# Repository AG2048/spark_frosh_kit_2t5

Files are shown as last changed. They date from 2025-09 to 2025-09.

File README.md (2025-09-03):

# Spark Design Club F!rosh Kit 2T5
F!rosh kit PCB design and programming files for F!rosh 2T5.

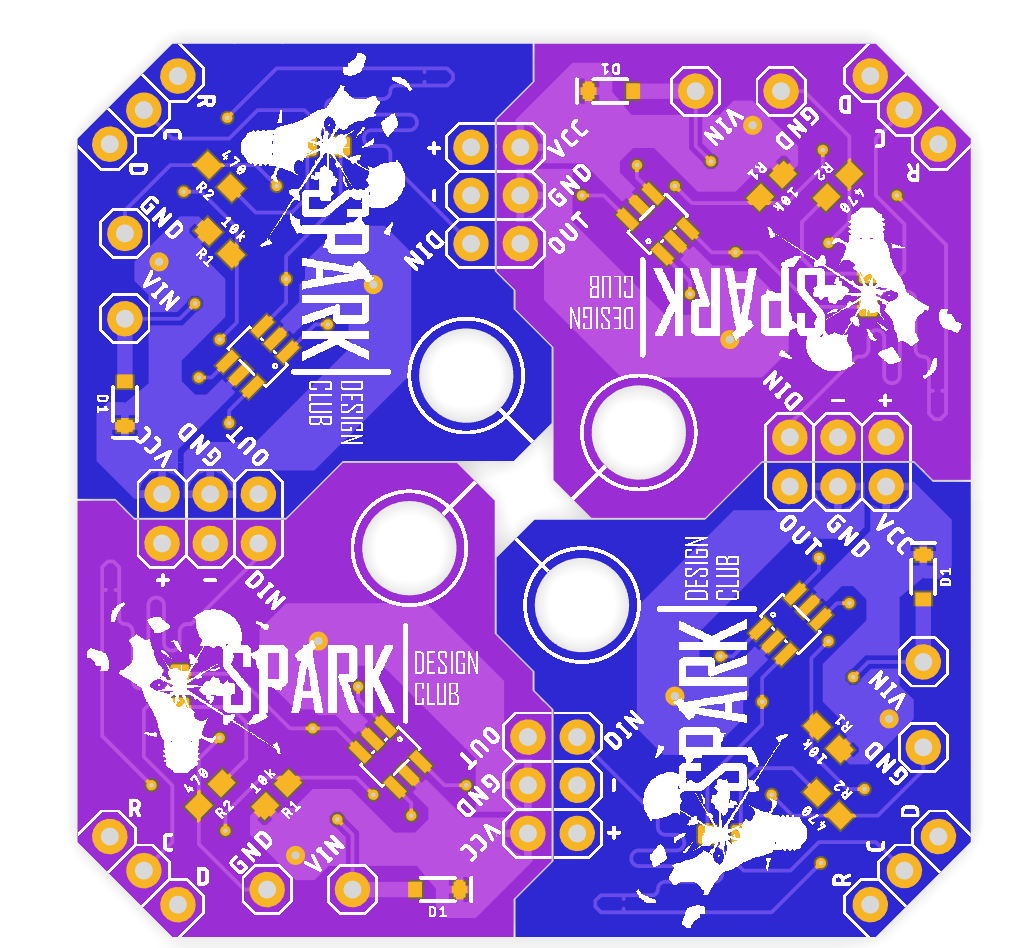
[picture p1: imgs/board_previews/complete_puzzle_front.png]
F!rosh Kit 2T5


# Description
The Spark F!rosh Kit 2T5 is a set of custom PCB designs featuring the Spark Design Club logo and branding. It is designed to act as a puzzle piece with two different color options. Each board of one colour can piece with two other boards of the other colour on two edges, and with 4 boards together, they form a loop in the shape of a large square!

This PCB features the ATTiny10 microcontroller, a small and versatile chip that can be easily powered, perfect for small, low-power applications like this F!rosh Kit PCB. Each board can communicate with the "downstream" board it is connected to and share power, with the ability to identify if the board itself has the "source power". 

The boards alone is a durable design for a keychain, showcasing your interest in electronics and design. When soldered, it can be used as a simple LED light source when powered. 

The real complex design of the boards comes into play when 4 soldered boards come together and form the larger square shape. When powered, these boards can be used to display more complex patterns!

The objective of this design is to make a cool-looking PCB, while also using its puzzle-like design to encourage F!rosh this year to meet new friends (reference: some old coca-cola commercial that did this...)

# File Structure
- `board_design_files/`: Contains the PCB design files for the F!rosh 2T5 kit. The BOM can also be found somewhere in this directory.
- `frosh_kit_program/`: Contains the Arduino program files for the F!rosh 2T5 kit.
- `imgs/`: Contains images related to the F!rosh 2T5 kit.
- `programming_resources/`: Contains resources for programming the ATTiny10 microcontroller. These files may be produced by other people. 

# Programming
The ATTiny10 microcontroller used in the F!rosh Kit can be programmed using the Tiny Programming Interface (TPI). The instruction to program the ATTiny10 using TPI was originally found on [this tutorial](https://make.kosakalab.com/make/electronic-work/arduio_tpi_en/). Unfortunately, as of September 1, 2025, this tutorial site is no longer available. Therefore, I have provided the necessary instructions below.

## Wire Connections
1. Prepare an Arduino UNO and 4 resistors (anywhere from 220Ω to 1kΩ should work).
2. Connect pin 10, 11, 12, and 13 of the Arduino UNO to the 4 resistors. Respectively, the other end of the resistors connected to pins 10, 11 and 12, and 13 represents `RESET`, `TPIDATA`, and `TPICLK`. (Image from the original tutorial)
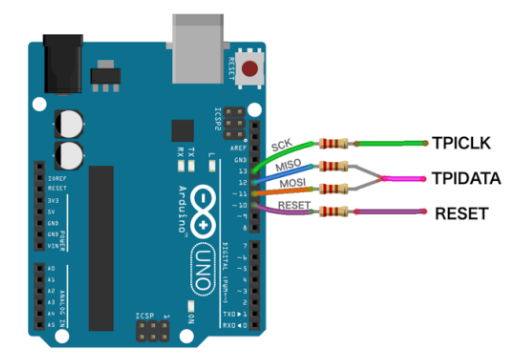
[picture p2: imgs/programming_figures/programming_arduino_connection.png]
Arduino Programming Connections

3. Connect `RESET` to the `R` pin, `TPIDATA` to the `D` pin, and `TPICLK` to the `C` pin. Also connect 5V to `VIN` or `+` or `VCC`, and ground to `GND` or `-`. The pins are visible from the front of the board:
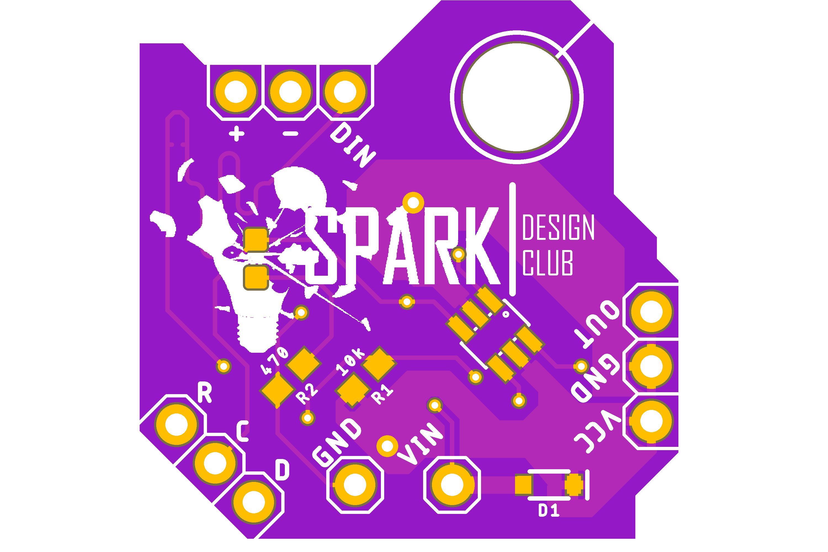
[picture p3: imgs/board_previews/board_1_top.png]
Board 1 Front View

- Note, if it's hard to connect to the `R`, `C`, `D` pins, you can connect `TPIDATA` to the `DIN` pin, and connect the `TPICLK` to the `CLK` pin. 

## Programming Environment Setup
1. Download the [modified Arduino programmer](programming_resources/ATtiny4_5_9_10_20_40Programmer_2/) obtained from the original tutorial.
2. Using the Arduino IDE, upload this sketch to the Arduino UNO.
3. Copy the following package.json URL to the Arduino IDE's Additional Board Manager URLs: `https://raw.githubusercontent.com/AG2048/spark_frosh_kit_2t5/refs/heads/main/programming_resources/package_bitDuino10-arduinoTPI_index.json` and click `OK`. (The original json file link is [here](https://kimio-kosaka.github.io/bitDuino10-arduinoTPI/package_bitDuino10-arduinoTPI_index.json), but a bug fix was needed to make this work on newer versions of Arduino IDE / AVR Board Packages)
4. Go to Tools > Board > Boards Manager, search for `bitduino`, and install `bitDuino10-aTPI`.
5. In Tools > Board, select `ATtiny10(bitDuino10-arduinoTPI)` as the active board, and select the port that the Arduino UNO is connected to. 

## Programming the ATTiny10
1. Load the (F!rosh Kit Program)[frosh_kit_program/] into the Arduino IDE.
2. Click the "Upload" button. 

## Notes:
The original package had a bug with the avr-gcc compiler version. Originally, it has to be set to version `5.4.0-atmel3.6.1-arduino2`, which forces users to use Arduino IDE 1.8.9 or less and version 1.6.23 of the Arduino AVR Boards platform. Details of this bug can be found in this [issue thread](https://github.com/kimio-kosaka/bitDuino10-arduinoTPI/issues/4#issuecomment-1046231772). 

As a fix, I adopted the solution mentioned in the issue thread, and made my [own copy of the package json file](programming_resources/package_bitDuino10-arduinoTPI_index.json) that adds the following package dependency specifications:

```json
      "toolsDependencies": [
        {
          "packager": "arduino",
          "name": "avr-gcc",
          "version": "5.4.0-atmel3.6.1-arduino2"
        },
        {
          "packager": "bitDuino10-aTPI",
          "name": "avrboy",
          "version": "1.0.1"
        }
      ]
```

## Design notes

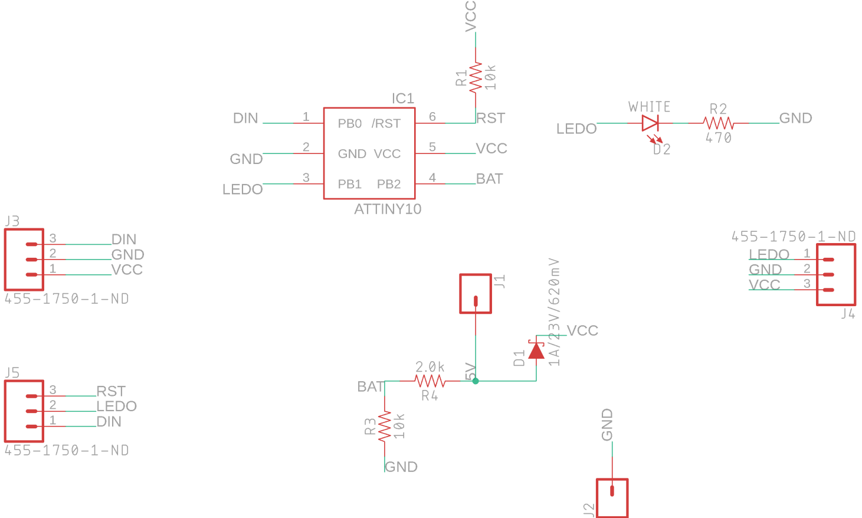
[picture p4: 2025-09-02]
imgs/schematics/schematic.png

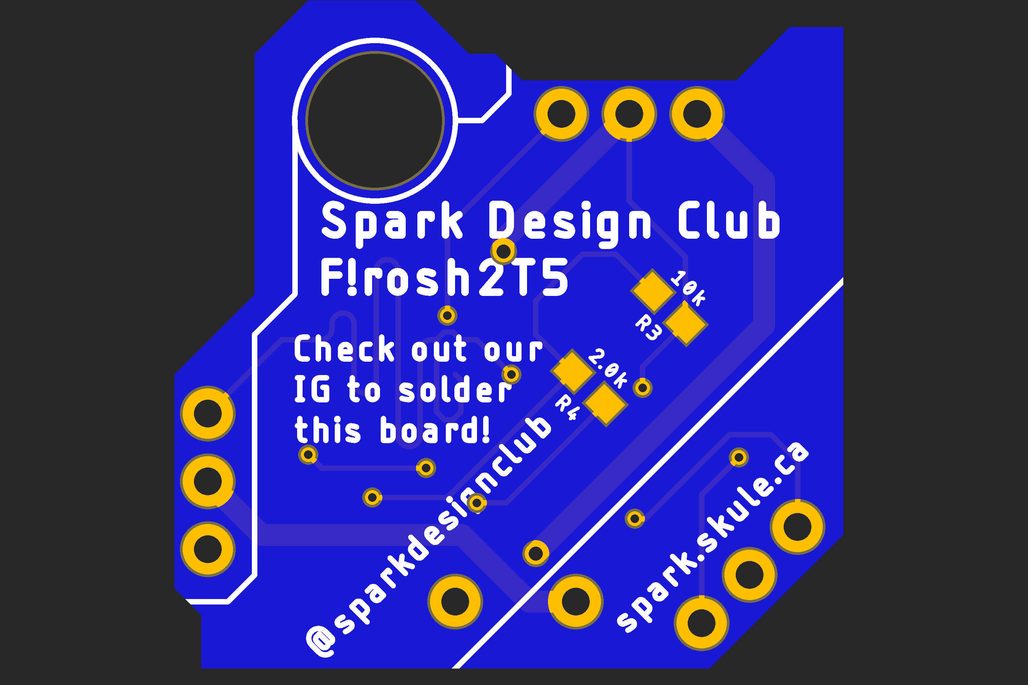
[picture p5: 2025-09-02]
imgs/board_previews/board_2_back.png

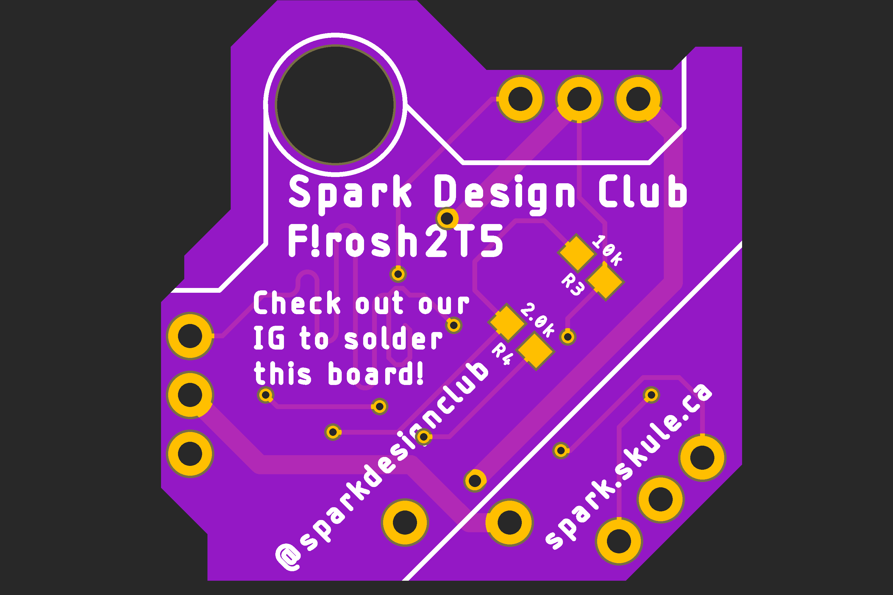
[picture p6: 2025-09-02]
imgs/board_previews/board_1_back.png

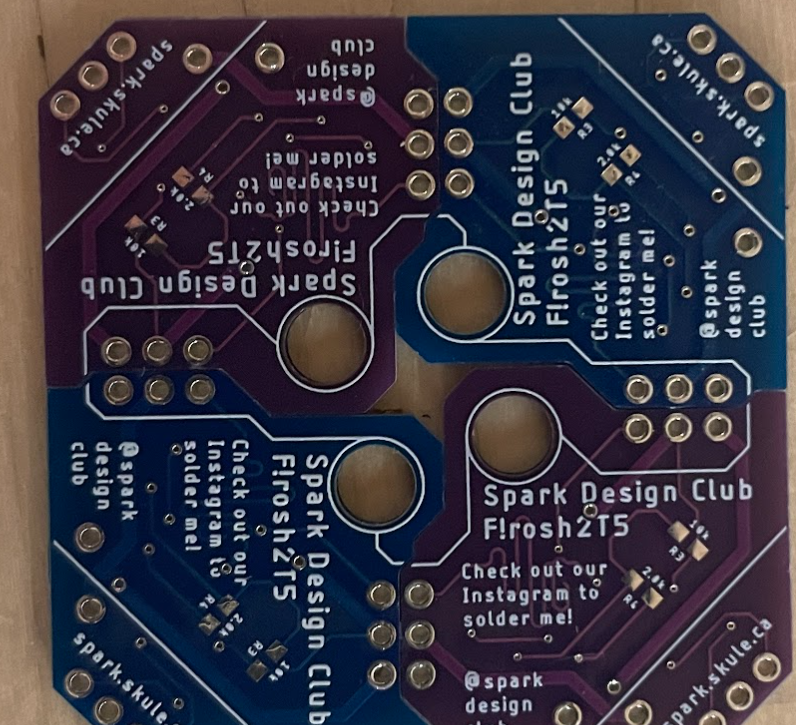
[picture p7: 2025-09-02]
imgs/produced_boards/four_boards_pieced_back.png

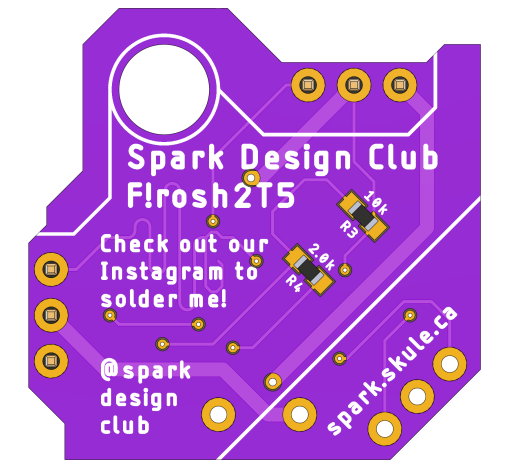
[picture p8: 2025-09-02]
imgs/board_previews/board_1_fusion_preview_back.png

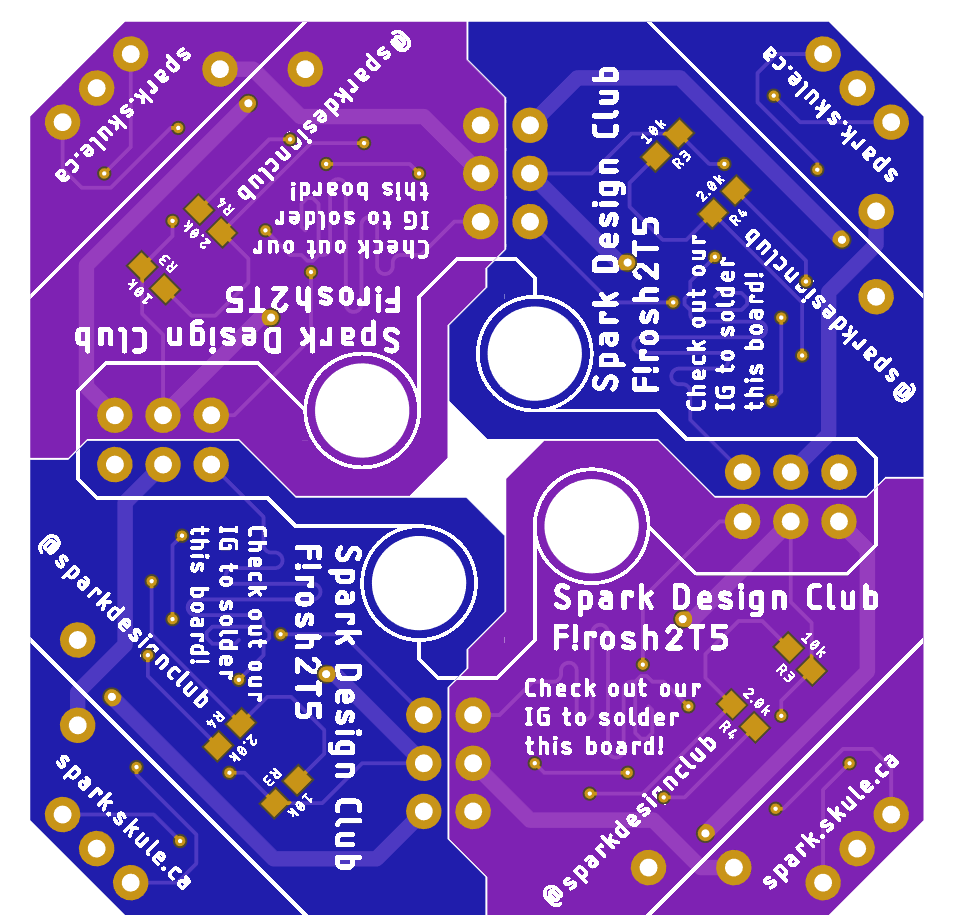
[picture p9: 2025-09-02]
imgs/board_previews/complete_puzzle_back.png

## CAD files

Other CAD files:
board_design_files/3d_models/SPARK_PCB_2025_BRD_1_3D.f3d
board_design_files/3d_models/SPARK_PCB_2025_BRD_2_3D.f3d

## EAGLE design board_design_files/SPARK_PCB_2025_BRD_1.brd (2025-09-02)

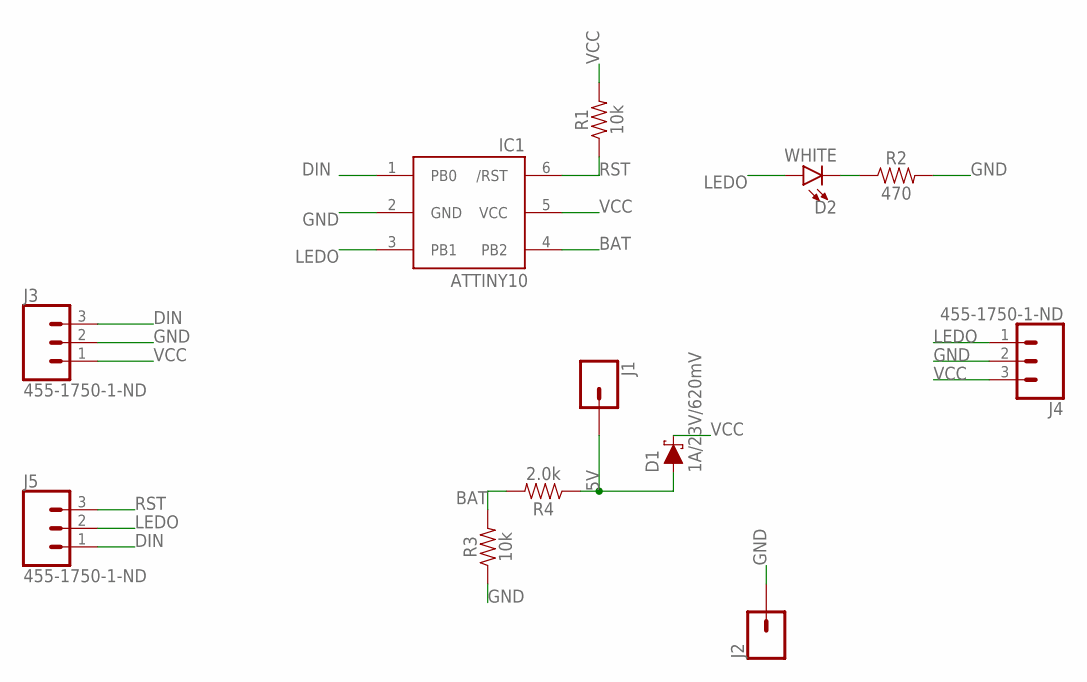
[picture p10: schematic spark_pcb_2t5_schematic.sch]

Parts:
D1: 1A/23V/620mV; SOD-323
D2: WHITE; LED-0603
IC1: ATTINY10; SOT23-6
J1, J2: CONN_01; 1X01
J3, J4, J5: 455-1750-1-ND; 1X03
R1, R3: 10k; 0603
R2: 470; 0603
R4: 2.0k; 0603

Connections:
5V: D1.A, J1.1, R4.1
BAT: IC1.4 (PB2), R3.2, R4.2
DIN: IC1.1 (PB0), J3.3, J5.1
GND: IC1.2 (GND), J2.1, J3.2, J4.2, R2.2, R3.1
LEDO: D2.A, IC1.3 (PB1), J4.1, J5.2
unnamed: D2.C, R2.1
RST: IC1.6 (/RST), J5.3, R1.1
VCC: D1.C, IC1.5 (VCC), J3.1, J4.3, R1.2

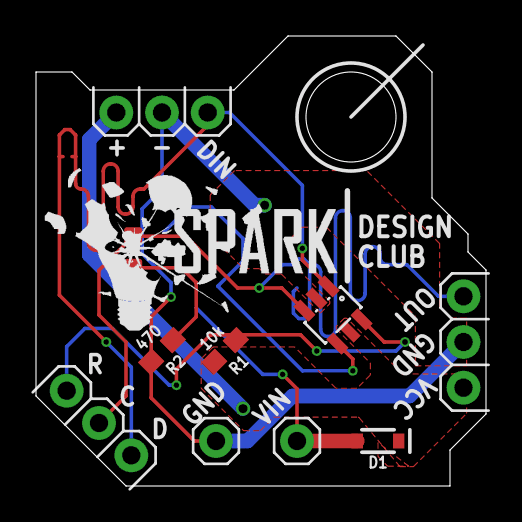
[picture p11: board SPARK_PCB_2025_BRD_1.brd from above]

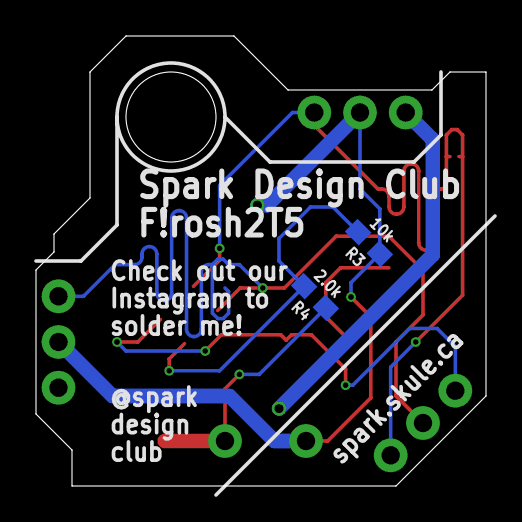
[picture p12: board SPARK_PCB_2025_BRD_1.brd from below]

Board: 2 copper layers, 25.0 x 25.0 mm, 12 parts (2 on the bottom side), 8 nets.

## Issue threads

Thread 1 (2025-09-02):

Some boards stuck ON when all 4 boards are connected

AG2048, 2025-09-02:
When all 4 boards are connected to each other, occasionally only 2 boards ever turn themselves off, while the two other boards stay on. When powering from different boards, sometimes all boards initializes properly and enter the sequence, while sometimes the boards get stuck in 2 always on, 2 always off state.

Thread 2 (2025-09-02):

Board final sequence stuck

AG2048, 2025-09-02:
After the board completed its final sequence of "speeding up cycle", the main board appears to become stuck in a forever LOW state, while all other boards are stuck in a forever ON state.

It's also noticed that right before entering the final cycle, the board PREVIOUS to the MAIN board lit up for a bit after it turned off, perhaps this caused some issue with cycle counting and led to the main board not receiving the last falling edge.

AG2048, 2025-09-02:
Commit af4958c:
Seems like the issue is caused by the lack of a delay between end of the TOGGLE sequence and the beginning of the cycle speed up sequence. What happened seems to be:

1. Board 4 finished its sequence, board 2 also finished its sequence. Both boards turned off.
2. Board 3 is still in its TOGGLE sequence, so board 3 saw board 2 turn off, and board 3 turned on. However, only for a split second (10ms)
3. Board 4 already is waiting for a falling edge as the speed up sequence, so it begin its first 250ms ON (this is supported by some slow-mo video recording of the boards in this error).
4. In the end, board 4 finishes its sequence before board 1 has a chance to wait for its falling edge. This causes board 1 to never see board 4's falling edge and stay off, while every other board completed its sequence and stays in ON state.

To resolve this, I added a 100ms delay between end of TOGGLE and beginning of CYCLE for both MAIN and SIDE boards, so that they all begin the cycle sequence with a guaranteed all-off state.

Closed 2025-09-02.

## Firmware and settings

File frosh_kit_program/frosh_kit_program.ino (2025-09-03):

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
// Define pin mappings corresponding to https://github.com/kimio-kosaka/bitDuino10-arduinoTPI/blob/master/variants/bitDuino10/pins_arduino.h
#define INPUT_PORT 0
#define OUTPUT_PORT 1
#define BATTERY_PORT 2

// Define delays for final circular output
#define X_INIT_VALUE 250
#define X_DEC_VALUE 25

// Global variables
bool is_main = false;
bool has_prev = false;
int x = X_INIT_VALUE;
int i = 0;

// Util functions to wait for signal edges
void wait_falling_edge() {
    while (digitalRead(INPUT_PORT) != 1);
    while (digitalRead(INPUT_PORT) != 0);
}

void wait_rising_edge() {
    while (digitalRead(INPUT_PORT) != 0);
    while (digitalRead(INPUT_PORT) != 1);
}

void wait_high(){
    while (digitalRead(INPUT_PORT) != 1);
}

void wait_low(){
    while (digitalRead(INPUT_PORT) != 0);
}

void setup() {
    // Initialize pin modes
    pinMode(INPUT_PORT, INPUT_PULLUP);
    pinMode(OUTPUT_PORT, OUTPUT);
    pinMode(BATTERY_PORT, INPUT);
    digitalWrite(OUTPUT_PORT, LOW);
    delay(500);

    // Determine if the device is the main one (based on BATTERY_PORT reading)
    if (digitalRead(BATTERY_PORT)) {
        is_main = true;
    } else {
        is_main = false;
    }

    // Determine if the board has any previous board attached
    if (digitalRead(INPUT_PORT) == LOW) {
        has_prev = true;
    } else {
        has_prev = false;
    }
    delay(500);
}

void loop() {
    if (!has_prev) {
        // In the event of the board having no previous board attached, do constant high
        digitalWrite(OUTPUT_PORT, HIGH);
    } else {
        // If the board has previous board connected, enable more complex patterns
        if (is_main) {
            // Main board initiates patterns

            // Initial ON/OFF 500ms
            digitalWrite(OUTPUT_PORT, HIGH);
            delay(500);
            digitalWrite(OUTPUT_PORT, LOW);
            delay(500);
            
            // First 250ms Loop
            digitalWrite(OUTPUT_PORT, HIGH);
            delay(250);
            digitalWrite(OUTPUT_PORT, LOW);
            wait_falling_edge();
            // Second 250ms Loop
            digitalWrite(OUTPUT_PORT, HIGH);
            delay(1000);

            // All turn off for a brief moment
            digitalWrite(OUTPUT_PORT, LOW);
            delay(10);

            // 500ms alternate
            digitalWrite(OUTPUT_PORT, HIGH);
            delay(500);
            digitalWrite(OUTPUT_PORT, LOW);
            delay(500);
            digitalWrite(OUTPUT_PORT, HIGH);
            delay(500);
            digitalWrite(OUTPUT_PORT, LOW);
            delay(500);

            // Speeding up
            delay(100);
            x = X_INIT_VALUE;
            while (x > X_DEC_VALUE) {
                digitalWrite(OUTPUT_PORT, HIGH);
                delay(x);
                digitalWrite(OUTPUT_PORT, LOW);
                x -= X_DEC_VALUE;
                wait_falling_edge();
            }

            // On 1500 before repeating
            digitalWrite(OUTPUT_PORT, HIGH);
            delay(1500);
        } else {
            // Secondary board follows main board's lead

            // Initially be equal to main until falling edge
            wait_high();
            digitalWrite(OUTPUT_PORT, HIGH);
            wait_falling_edge(); // If main board has no previous board, this falling edge will never be reached
            digitalWrite(OUTPUT_PORT, LOW);

            // Loop 1
            wait_falling_edge();
            digitalWrite(OUTPUT_PORT, HIGH);
            delay(250);
            digitalWrite(OUTPUT_PORT, LOW);

            // Loop 2 -- keep on after
            wait_high();
            delay(250);
            digitalWrite(OUTPUT_PORT, HIGH);

            // Wait for falling edge initiated by main
            wait_falling_edge();
            digitalWrite(OUTPUT_PORT, LOW);
            
            // The next alternating sequence will last 2000 ms, so do 10ms periodic check
            for (i = 0; i < 200; i++) {
                delay(10);
                if (digitalRead(INPUT_PORT) == LOW) {
                    digitalWrite(OUTPUT_PORT, HIGH);
                } else {
                    digitalWrite(OUTPUT_PORT, LOW);
                }
            }

            // Write LOW to begin the final cycle
            digitalWrite(OUTPUT_PORT, LOW);
            delay(100);

            // Cycle: light after falling edge, duration speeds up
            x = X_INIT_VALUE;
            while (x > X_DEC_VALUE) {
                wait_falling_edge();
                digitalWrite(OUTPUT_PORT, HIGH);
                delay(x);
                digitalWrite(OUTPUT_PORT, LOW);
                x -= X_DEC_VALUE;
            }

            // On 1500 before repeating
            digitalWrite(OUTPUT_PORT, HIGH);
            delay(1500);
        }
    }
}

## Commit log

2025-09-02 Add bitDuino10-arduinoTPI package index
    Introduces package_bitDuino10-arduinoTPI_index.json for Arduino board and tool definitions, enabling support for ATtiny10(arduinoTPI) and avrboy tool across multiple platforms.
2025-09-02 Add SPARK PCB 2025 board and CAM files
    Initial commit of SPARK PCB 2025 board design files, including two board layouts, 3D models, CAM outputs (Gerber, drill, ODB, and assembly files), and schematic. This provides all necessary files for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
    [SPARK_PCB_2025_BRD_1.brd, SPARK_PCB_2025_BRD_1_3D.f3d, SPARK_PCB_2025_BRD_2.brd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]
2025-09-02 Add board preview, produced board, and schematic images
    Added new images for board previews, produced boards, programming figures, renders, and schematics to support documentation and visualization of hardware and assembly processes.
2025-09-02 Add ATtiny TPI programmer Arduino sketch
    Initial commit of ATtiny4/5/9/10/20/40 programmer for Arduino, supporting TPI programming via serial commands. Includes memory dump, chip erase, program writing, fuse and lock bit management, device 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
2025-09-02 Add initial frosh kit PCB program
    Implements the main logic for the Spark Design Club 2T5 F!rosh PCB, including pin setup, main/secondary board detection, and output patterns based on board configuration. This is the initial version 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
2025-09-02 Update README.md
    Adding reminder to connect power when programming.
2025-09-02 Update README.md
    Clearer pin names in programming instruction
2025-09-02 Add delay to setup before turning light on
    Issue #1: Previously, some board may have completed the "has_prev" check too quickly, and begin turning itself on without allowing the next board to read its "off" state. Adding a long delay makes sure all boards can read a "previous board low" before proceeding into loop()
    [frosh_kit_program.ino]
2025-09-02 Resolve board not completing final cycle
    From Issue #2, there were no delay between the end of the toggle sequence to when the side boards first detect falling edges. This, in combination of the constant toggle behaviour for the toggle pattern, may have caused the following sequence: board 4 finished sequence and now waiting for falling edge, board 2 finished sequence turned off, board 3 still in sequence and turned on for a bit and its sequence ended, board 4 saw the on-off sequence for 10ms, triggering its first falling edge. This is supported by the fact that this last board 4 lit up for approximately 250 ms.
    This is resolved by adding a short delay after the toggle sequence, making sure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
    [frosh_kit_program.ino]
2025-09-03 #3 Fix increase delay duration
    Previous 800ms delay forgot to consider the duration the last LED should've been on as well. To make the timing consistent, last LED should also have a delay time of 250 ms. Thus making the delay after the don't turn off loop 1000ms should solve this issue
    [frosh_kit_program.ino]
2025-09-03 Update README with better programming instructions
    Clarified the programming section for the ATTiny10 microcontroller, corrected pin mappings, and added notes for alternative connections. Also updated the board design files description to mention the BOM location.

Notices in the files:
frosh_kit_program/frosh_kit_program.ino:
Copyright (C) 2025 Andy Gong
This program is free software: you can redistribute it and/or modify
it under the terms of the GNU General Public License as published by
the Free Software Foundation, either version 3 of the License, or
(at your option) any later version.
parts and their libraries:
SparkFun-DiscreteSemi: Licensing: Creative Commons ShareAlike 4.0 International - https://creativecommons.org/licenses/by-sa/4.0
